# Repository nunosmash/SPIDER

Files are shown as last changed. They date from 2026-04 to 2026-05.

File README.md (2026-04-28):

[README.md](https://github.com/user-attachments/files/26697123/README.md)
# SPIDER

**BLE MIDI gateway** — bridge **Bluetooth LE MIDI** controllers to **USB MIDI** and **DIN MIDI**, with up to **three** simultaneous BLE devices, **fixed slot routing**, and **HOST** / **CLIENT** roles for stage and DAWless setups.

Part of the **Ash Sound Works** custom tools for live and studio — by sound artist and producer **Ash (Ahn Sunghoon)** · [GitHub](https://github.com/nunosmash) / 
[Manual](http://ashsoundworks.com/spider-manual.html)

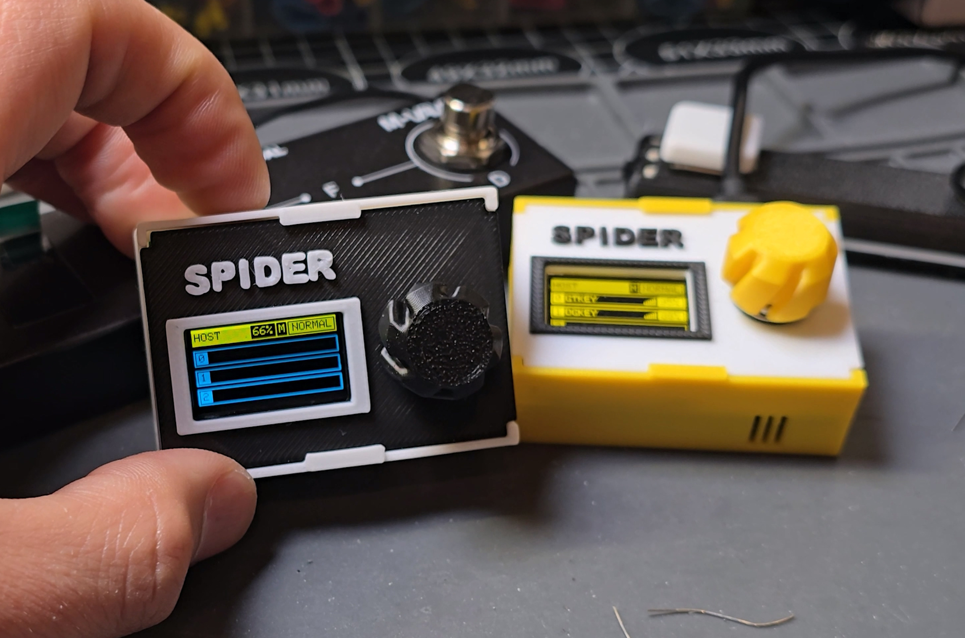
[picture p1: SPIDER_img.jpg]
SPIDER (https://youtu.be/Al2et1Eq5mc?si=DPkdCoxhtiU5xMxv)


---

## Why SPIDER?

Running cables across a crowded **pedalboard** or needing **remote** control for other players is awkward. SPIDER was built around **BLE MIDI** on a dedicated **nRF52840** radio (e.g. **nice!nano** class hardware): low power, battery-friendly, and focused on **wireless MIDI** rather than sharing the stack with a desktop OS BLE stack.

---

## Key features

- Up to **3** BLE MIDI controllers connected at once  
- **USB MIDI** via **TinyUSB** — **3 independent virtual MIDI ports** (one per slot)  
- **DIN MIDI** — **Slot 0** routes to DIN when appropriate (see routing below)  
- **7.5 ms** BLE connection interval class; low-latency slot timing (~**5 ms** average response in typical use)  
- **TX power** auto-adjust **0 ~ +8 dBm** from **RSSI**  
- **Battery monitoring** for the unit and connected gear (where supported)  
- **OLED** UI with power-save brightness (USB vs battery profiles)  
- **HOST** and **CLIENT** modes  

---

## Routing architecture

| Role | Behavior (summary) |
|---|---|
| **Slot 0 (master)** | USB ↔ BLE ↔ DIN MIDI |
| **Slots 1–2** | USB ↔ BLE |
| **Port pinning** | Each slot stores **MAC + name** so devices **always** map to the same slot regardless of power-on order |

### HOST mode

- **USB data connected:** BLE → **USB MIDI** (DIN blocked for that path per firmware logic)  
- **No USB data:** Slot 0 → **DIN MIDI** output  
- Slot management: **RESCAN**, **CLEAR SLOT**, auto-reconnect  

### CLIENT mode

- Uses **one slot** to join a host  
- Remembers first trusted host **MAC** (save window ~30 s on first connect); optional **block** for unwanted devices  

---

## OLED / status (summary)

- Top line: **LOW BAT**, **WEAK SIG**, **M** (DIN active), TX power hints  
- Per slot: **EMPTY** / **OFFLINE** / **CONNECTED**  
- MIDI traffic: ▽ in / △ out  
- Battery: **%** or **N/A** if unknown  

### Antenna bars (signal guide)

- **6–4 bars** — best; within ~**10 m** reliable  
- **3 bars** — stable for normal use  
- **≤2 bars** — TX power ramps up; maintain connection  
- **0 bars** — unreliable; move closer  

**Tip:** Keep **3+ bars** within ~**10 m** for dependable live use.

---

## Ableton Live (quick setup)

**Preferences → Link / Tempo / MIDI**

- **Input:** SPIDER MIDI **Port 1, 2, 3** → **Track** ON, **Remote** ON as needed  
- **Output:** enable if you send MIDI back to wireless gear  

| Slot | USB MIDI port |
|---|---|
| SLOT 1 | Port 1 |
| SLOT 2 | Port 2 |
| SLOT 3 | Port 3 |

---

## Sync calibration

BLE adds variable delay; align with audio using **Track Delay** like any MIDI path. Many setups start around **−10 ms ~ −20 ms** (often **−18 ms**) and refine by recording MIDI out + external audio and matching to the grid.

---

## Firmware update

1. Connect SPIDER over **USB**.  
2. Hold the **encoder button** for **5+ seconds** to enter firmware update mode (**USB mass storage** / removable drive).  
3. Copy the released firmware file to the mounted drive; device updates and reboots.  

(Exact filename and format follow your published release notes.)

---

## Use cases

- **Band live** — multiple wireless controllers into one DAW reliably  
- **DAWless** — Slot 0 → hardware synths via DIN  
- **Multi-computer** — advanced MIDI routing between several hosts (see full manual)  

---

## Repository contents

Depending on branch or release:

- Firmware (Zephyr / Arduino / etc. — match your repo)  
- Schematics / PCB / case files  
- Build and flash instructions  

Full wiring, menus, and edge cases: **`spider-manual.html`** in the Ash Sound Works bundle.

---

## Hardware Specifications (BOM)

| Category | Component Description | Qty |
| :--- | :--- | :---: |
| **MCU** | nRF52840 (nice!nano v2.0 SuperMini) | 1 |
| **Display** | 0.91" OLED Module (128x64) | 1 |
| **Optocoupler** | 6N138 High-Speed Optocoupler | 1 |
| **Diode** | 1N4001 Rectifier Diode | 1 |
| **Capacitor** | 100μF Electrolytic Capacitor | 1 |
| **Input** | EC11 Rotary Encoder w/ Push Switch | 1 |
| **Connectors** | PJ-320A 3.5mm Stereo Jack | 2 |
| **Power** | SS-12F23 Slide Switch | 1 |
| **Resistors** | 220Ω (x2), 330Ω (x2), 150Ω, 1kΩ, 4.7kΩ, 10Ω, 30Ω | 9 |

## Documentation

- Full manual: `spider-manual.html`  
- Other projects: [github.com/nunosmash](https://github.com/nunosmash)

---

## Disclaimer

- **BLE** performance depends on environment, antennas, and interference — always **test** before a show.  
- Verify **DIN polarity** (Type A/B) when connecting legacy MIDI gear.  
- DIY: observe battery and USB power safety.

---

## License

See the `LICENSE` file in the repository root.

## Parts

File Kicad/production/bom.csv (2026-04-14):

Designator | Footprint | Quantity | Value | LCSC Part #
1N4001 | D_DO-35_SOD27_P7.62mm_Horizontal | 1 | 1n4001
C1 | CP_Radial_D6.3mm_P2.50mm | 1 | 100uF
ENC5 | RotaryEncoder_Alps_EC11E-Switch_Vertical_H20mm | 1 | EC11
J1 | PinHeader_1x02_P2.54mm_Vertical | 1 | BATTERY
J2 | PJ-320A | 1 | MIDI IN ◁
J3 | PJ-320A | 1 | MIDI OUT
R10 | R_Axial_DIN0204_L3.6mm_D1.6mm_P7.62mm_Horizontal | 1 | 4.7k
R13, R14 | R_Axial_DIN0204_L3.6mm_D1.6mm_P7.62mm_Horizontal | 2 | 330
R19 | R_Axial_DIN0204_L3.6mm_D1.6mm_P7.62mm_Horizontal | 1 | 10
R20 | R_Axial_DIN0204_L3.6mm_D1.6mm_P7.62mm_Horizontal | 1 | 30
R4, R8 | R_Axial_DIN0204_L3.6mm_D1.6mm_P7.62mm_Horizontal | 2 | 220
R5 | R_Axial_DIN0204_L3.6mm_D1.6mm_P7.62mm_Horizontal | 1 | 150
R9 | R_Axial_DIN0204_L3.6mm_D1.6mm_P7.62mm_Horizontal | 1 | 1k
SW1 | SS-12F23 | 1 | SW_SPDT
U2 | DIP-8_W7.62mm | 1 | 6N138
U3 | 128x64OLED | 1 | OLED-I2C

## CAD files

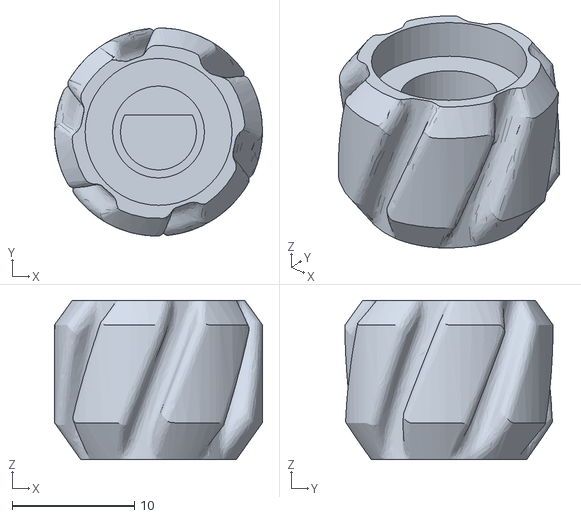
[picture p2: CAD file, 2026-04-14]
Case/SPIDER_CASE_KNOB.stl
17.0 x 17.0 x 13.0

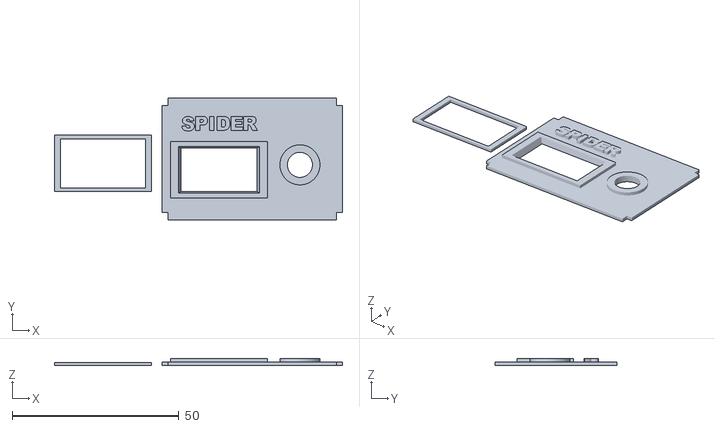
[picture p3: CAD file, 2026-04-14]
Case/SPIDER_CASE_TOP.stl
86.2 x 36.5 x 2.00

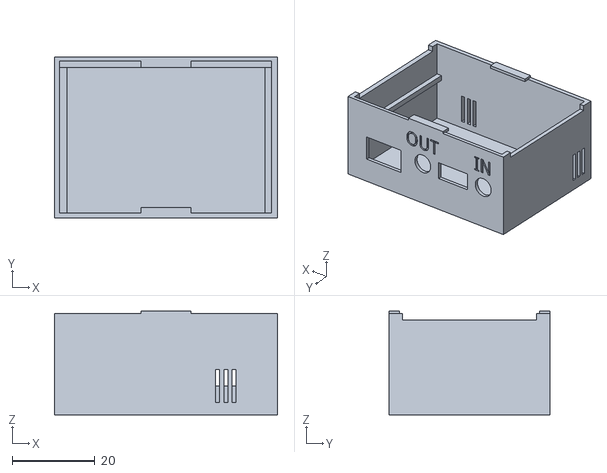
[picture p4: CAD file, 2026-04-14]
Case/SPIDER_CASE_BOTTOM(BAT).stl
54.0 x 39.0 x 25.1

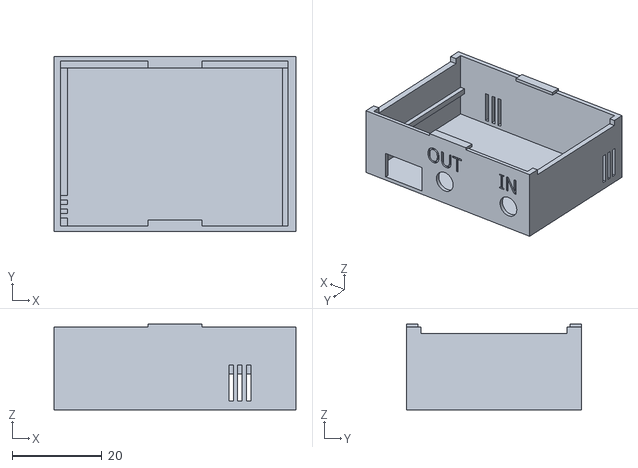
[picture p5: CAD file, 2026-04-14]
Case/SPIDER_CASE_BOTTOM.stl
54.0 x 39.0 x 19.1

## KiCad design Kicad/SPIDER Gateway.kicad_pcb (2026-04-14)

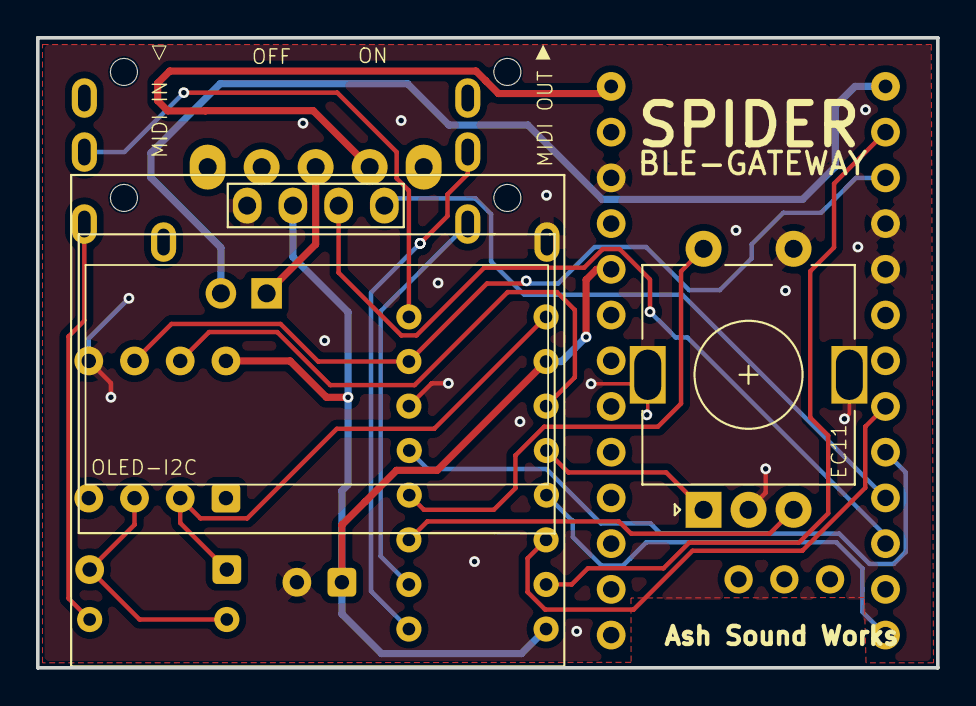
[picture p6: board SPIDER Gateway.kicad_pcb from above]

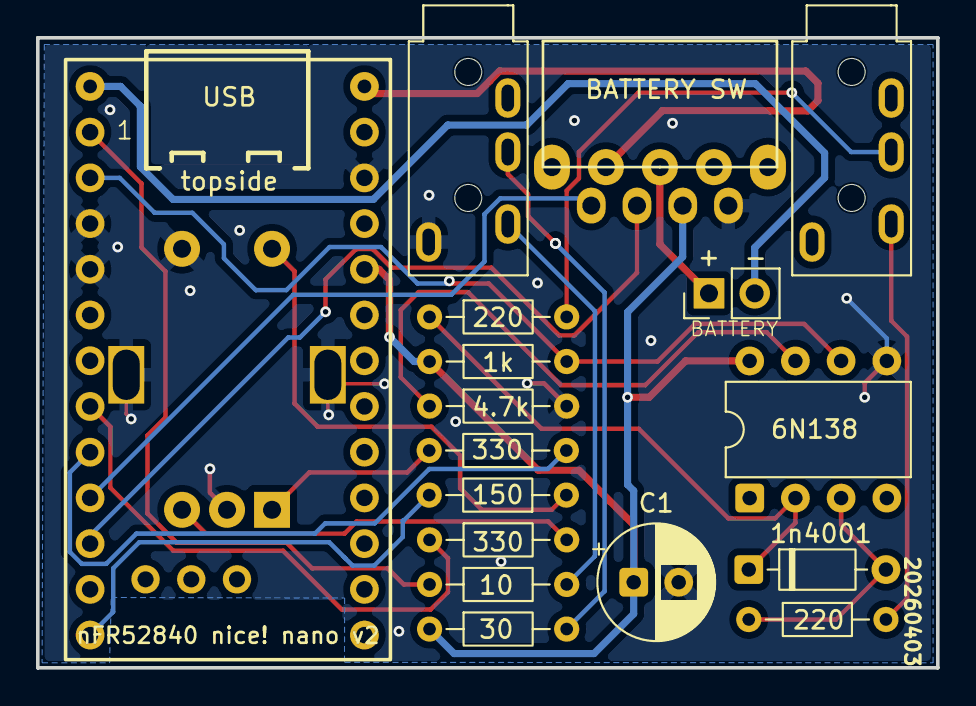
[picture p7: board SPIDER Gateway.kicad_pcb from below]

Board: 2 copper layers, 50.0 x 35.0 mm, 19 parts (17 on the bottom side), 22 nets.

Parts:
1n4001: 1n4001; D_DO-35_SOD27_P7.62mm_Horizontal
C1: 100uF; CP_Radial_D6.3mm_P2.50mm
Enc5: EC11; RotaryEncoder_Alps_EC11E-Switch_Vertical_H20mm
J1: BATTERY; PinHeader_1x02_P2.54mm_Vertical
J2: MIDI IN ◁; PJ-320A
J3: MIDI OUT; PJ-320A
R4, R8: 220; R_Axial_DIN0204_L3.6mm_D1.6mm_P7.62mm_Horizontal
R5: 150; R_Axial_DIN0204_L3.6mm_D1.6mm_P7.62mm_Horizontal
R9: 1k; R_Axial_DIN0204_L3.6mm_D1.6mm_P7.62mm_Horizontal
R10: 4.7k; R_Axial_DIN0204_L3.6mm_D1.6mm_P7.62mm_Horizontal
R13, R14: 330; R_Axial_DIN0204_L3.6mm_D1.6mm_P7.62mm_Horizontal
R19: 10; R_Axial_DIN0204_L3.6mm_D1.6mm_P7.62mm_Horizontal
R20: 30; R_Axial_DIN0204_L3.6mm_D1.6mm_P7.62mm_Horizontal
SW1: SW_SPDT; SS-12F23
U1: nFR52840 nice! nano v2; SuperMini NRF52840
U2: 6N138; DIP-8_W7.62mm
U3: OLED-I2C; 128x64OLED

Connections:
3.3V VCC: C1.1, R9.1, R20.1, U1.16 (3V3), U2.8 (VCC), U3.2 (VCC)
BATTERY +: J1.1, SW1.2 (B)
BATTERY -: J1.2, U1.28 (GND)
ENC A: R13.1, U1.8 (P0.24)
ENC B: R14.1, U1.7 (P0.22)
GND: C1.2, Enc5.C, Enc5.MP, Enc5.S1, J3.S, R10.2, U1.3 (GND), U1.4 (GND), U1.14 (GND), U2.5 (GND), U3.1 (GND)
unnamed: 1n4001.2 (A), R4.1, U2.3 (C2)
unnamed: 1n4001.1 (K), R8.1, U2.2 (C1)
unnamed: Enc5.A, R13.2
unnamed: Enc5.B, R14.2
unnamed: Enc5.S2, R5.1
unnamed: J2.R1, R8.2
unnamed: J2.T, R4.2
unnamed: J3.R1, R20.2
unnamed: J3.T, R19.2
unnamed: SW1.3 (C), U1.29 (BAT+)
unnamed: R10.1, U2.7 (VO1)
RX: R9.2, U1.2 (P0.08), U2.6 (VO2)
SCK: U1.10 (P0.11), U3.3 (SCL)
SDA: U1.9 (P1.00), U3.4 (SDA)
SW: R5.2, U1.12 (P1.06-LF)
TX: R19.1, U1.1 (P0.06)

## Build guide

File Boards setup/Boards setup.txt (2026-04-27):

How to set pin numbers for nRF52840 nice!nano v2.0

Refer to:
https://github.com/pdcook/nRFMicro-Arduino-Core?tab=readme-ov-file

Replace the variant.h and variant.cpp files located in a path similar to:
C:\Users\Administrator\AppData\Local\Arduino15\packages\adafruit\hardware\nrf52\1.7.0\variants\feather_nrf52840_express

How to change TinyUSB serial name

Raspberry Pi Pico 2
C:\Users\Administrator\AppData\Local\Arduino15\packages\rp2040\hardware\rp2040\5.4.4\libraries\Adafruit_TinyUSB_Arduino\src\arduino

nRF52840
C:\Users\Administrator\AppData\Local\Arduino15\packages\adafruit\hardware\nrf52\1.7.0\libraries\Adafruit_TinyUSB_Arduino\src\arduino

Go to the corresponding path and edit the Adafruit_USBD_CDC.cpp file.
Find setStringDescriptor("TinyUSB Serial"); and change the string inside the quotes to modify the name shown when connecting the board via serial.

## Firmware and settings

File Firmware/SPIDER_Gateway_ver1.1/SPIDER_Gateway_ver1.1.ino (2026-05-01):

// =============================================================================
// SPIDER Gateway — nRF52840 (Nice!nano) BLE MIDI bridge + OLED UI
// =============================================================================

#include <bluefruit.h>
#include <Wire.h>
#include <Adafruit_GFX.h>
#include <Adafruit_SSD1306.h>
#include <InternalFileSystem.h>
#include <Adafruit_SleepyDog.h>
#include <Adafruit_TinyUSB.h>

// -----------------------------------------------------------------------------
// USB MIDI: host(3 ports) / client(1); active pointer set in setup()
// -----------------------------------------------------------------------------
Adafruit_USBD_MIDI usb_midi_host(3);
Adafruit_USBD_MIDI usb_midi_client(1);
Adafruit_USBD_MIDI *usb_midi_ptr = nullptr;

#define MIDI_SVC_UUID_STR "03b80e5a-ede8-4b33-a751-6ce34ec4c700"
#define MIDI_CHR_UUID_STR "7772e5db-3868-4112-a1a9-f2669d106bf3"

#define MY_USB_MANUFACTURER "ASH SOUND WORKS"
#define MY_USB_PRODUCT "SPIDER"
#define MY_USB_PID 0x033A
#define MY_USB_SERIAL "0001"
#define usb_midi (*usb_midi_ptr)

#define MAGIC_UF2_BOOTLOADER 0x57

// -----------------------------------------------------------------------------
// BLE central (host): battery client + 3x MIDI + 3x battery services
// -----------------------------------------------------------------------------
BLEClientService host_bat_svc_client(UUID16_SVC_BATTERY);
BLEClientCharacteristic host_bat_chr_client(UUID16_CHR_BATTERY_LEVEL);
BLEUuid midiSvcUuid(MIDI_SVC_UUID_STR);
BLEUuid midiChrcUuid(MIDI_CHR_UUID_STR);
BLEClientService ble_midi_svc[3] = {
  BLEClientService(midiSvcUuid), BLEClientService(midiSvcUuid), BLEClientService(midiSvcUuid)
};
BLEClientCharacteristic ble_midi_chr[3] = {
  BLEClientCharacteristic(midiChrcUuid), BLEClientCharacteristic(midiChrcUuid), BLEClientCharacteristic(midiChrcUuid)
};
BLEClientService ble_bat_svc[3] = {
  BLEClientService(UUID16_SVC_BATTERY), BLEClientService(UUID16_SVC_BATTERY), BLEClientService(UUID16_SVC_BATTERY)
};
BLEClientCharacteristic ble_bat_chr[3] = {
  BLEClientCharacteristic(UUID16_CHR_BATTERY_LEVEL), BLEClientCharacteristic(UUID16_CHR_BATTERY_LEVEL), BLEClientCharacteristic(UUID16_CHR_BATTERY_LEVEL)
};

using namespace Adafruit_LittleFS_Namespace;

// -----------------------------------------------------------------------------
// Filesystem / scan list / pins
// -----------------------------------------------------------------------------
#define CONFIG_FILE "/slots_config.dat"
#define MAX_DEVICES 50
#define NAME_LEN 15
#define DEVICE_TIMEOUT 3000

#define SDA_PIN 6
#define SCL_PIN 7
#define VCC_EXT_PIN 21
#define ENCODER_A 4
#define ENCODER_B 5
#define BUTTON_PIN 9

// -----------------------------------------------------------------------------
// Display, encoder, UI timing
// -----------------------------------------------------------------------------
uint8_t ignoredMac[6] = { 0 };
uint32_t ignoreUntil = 0;
uint8_t pendingUnknownMac[6] = { 0 };
unsigned long pendingUnknownSince = 0;
/** 블랙리스트 중인 피어 표시용 (CLEAR&BLOCK 시 clientSlot 이름 복사) */
char ignoredPeerName[NAME_LEN] = "";
unsigned long searchStartTime = 0;
Adafruit_SSD1306 display(128, 64, &Wire, -1);
long encoderPos = 0;
/** A=bit1, B=bit0 — AB 인터럽트 전이표용 이전 상태 */
volatile uint8_t encPrevState = 0;
bool buttonState = false;
int currentSelection = -1;
unsigned long lastInteractionTime = 0;
int displayDeviceCount = 0;
uint8_t lockedMac[6] = { 0 };
bool isTargetLocked = false;
bool isBackSelected = false;
ble_gap_evt_adv_report_t device_reports[MAX_DEVICES];
unsigned long lastMidiTime[3] = { 0, 0, 0 };
unsigned long lastUsbMidiTime[3] = { 0, 0, 0 };
volatile int encoderAccumulator = 0;
/** 디텐트당 LUT 누적(보통 4; 메뉴가 2칸씩 움직이면 2로 낮춤) */
const int ENC_STEPS_PER_DETENT = 4;
unsigned long lastEncoderMoveTime = 0;
const unsigned long ENCODER_GAP = 0;
uint8_t remoteHostBat = 0;
bool blinkState = false;


// -----------------------------------------------------------------------------
// BLE peripheral (client): 128-bit MIDI UUID (little-endian byte order)
// -----------------------------------------------------------------------------
const uint8_t UUID128_SVC_MIDI[] = {
  0x00, 0xC7, 0xC4, 0x4E, 0xE3, 0x6C, 0x51, 0xA7,
  0x33, 0x4B, 0xE8, 0xED, 0x5A, 0x0E, 0xB8, 0x03
};
const uint8_t UUID128_CHR_MIDI[] = {
  0xF3, 0x6B, 0x10, 0x9D, 0x66, 0xF2, 0xA9, 0xA1,
  0x12, 0x41, 0x68, 0x38, 0xDB, 0xE5, 0x72, 0x77
};
BLEService client_midi_svc = BLEService(UUID128_SVC_MIDI);
BLECharacteristic client_midi_chr = BLECharacteristic(UUID128_CHR_MIDI);
BLEBas client_bat;
int lastRemainingSeconds = -1;

unsigned long scanStartTime = 0;
const unsigned long UI_TIMEOUT = 7000;
const unsigned long DIM_TIMEOUT = 300000;
/** 클라이언트: 플래시에 마스터 없을 때만 첫 연결 후 자동 저장까지 카운트다운(초). 15초로 줄이려면 15000UL */
const unsigned long CLIENT_TRUST_SAVE_MS = 30000UL;
bool isDimmed = false;
String pendingName = "";
char errorMsg[20] = "";
unsigned long errorMsgUntil = 0;
/** BLE 콜백에서 OLED(I2C)를 직접 건드리지 않고, loop()에서 updateDisplay()만 호출하도록 요청 */
volatile bool g_displayRefreshRequest = false;
static bool g_displayReady = false;

enum SystemMode { MODE_HOST,
                  MODE_CLIENT };

SystemMode loadSystemMode();
void showSetupProgress(const char *msg);
void setupHostMode();
void setupClientMode();

enum TxPowerMode { POWER_NORMAL,
                   POWER_STRONG,
                   POWER_BOOST };
TxPowerMode currentTxMode = POWER_NORMAL;
int8_t activeTxPower = 0;

enum ConnectionMatchMode { MATCH_MAC_ONLY = 0,
                           MATCH_MAC_AND_NAME = 1 };
ConnectionMatchMode currentConnectionMatchMode = MATCH_MAC_AND_NAME;
void drawConnectionModeMenu();
void saveConnectionMatchMode(ConnectionMatchMode mode);
ConnectionMatchMode loadConnectionMatchMode();
void drawEncoderDirectionMenu();
void drawSetupMenu();
void saveEncoderReversed(bool reversed);
bool loadEncoderReversed();

struct Device {
  uint8_t mac[6];
  int8_t rssi;
  char name[NAME_LEN];
  unsigned long lastSeen;
};

enum State { MAIN_MENU,
             SLOT_MENU,
             SCAN_MENU,
             MODE_SELECT,
             CLIENT_MENU,
             CONNECTION_MODE_MENU,
             ENCODER_DIRECTION_MENU,
             SETUP_MENU };
State currentState = MAIN_MENU;
SystemMode currentSystemMode = MODE_HOST;
int modeSelection = 0;
int clientMenuSelection = 0;
unsigned long buttonPressStartTime = 0;
bool isEncoderReversed = false;

enum SlotStatus { EMPTY,
                  OFFLINE,
                  CONNECTED };

struct Slot {
  SlotStatus status;
  char name[NAME_LEN];
  uint8_t mac[6];
  int8_t battery;
};

struct SystemSettings {
  uint8_t savedMasterMac[6];
  char savedMasterName[NAME_LEN];
  bool hasSavedMaster;
};

SystemSettings config = { { 0 }, "", false };
unsigned long connectionStartTime = 0;
bool isMasterSavedThisSession = false;
typedef Slot SlotConfig;

int slotMenuSelection = 0;
int selectedSlotIdx = -1;
int scanMenuSelection = 0;
int connectionModeSelection = 0;
int encoderDirectionSelection = 0;
int setupMenuSelection = 0;

bool macEqual(const uint8_t *a, const uint8_t *b) {
  for (int i = 0; i < 6; i++) {
    if (a[i] != b[i]) return false;
  }
  return true;
}

// -----------------------------------------------------------------------------
// Slots & scan device list
// -----------------------------------------------------------------------------
Slot slots[3] = {
  { EMPTY, "", { 0 }, -1 },
  { EMPTY, "", { 0 }, -1 },
  { EMPTY, "", { 0 }, -1 }
};
Slot clientSlot = { EMPTY, "", { 0 }, -1 };

bool isScanRequired() {
  if (currentState == SCAN_MENU) return true;
  for (int i = 0; i < 3; i++) {
    if (slots[i].status == OFFLINE) return true;
  }
  return false;
}

Device devices[MAX_DEVICES];
int deviceCount = 0;

// -----------------------------------------------------------------------------
// Config file (host slots + client master info)
// -----------------------------------------------------------------------------
void saveConfig() {
  Watchdog.reset();
  SlotConfig toSave[3];

  if (currentSystemMode == MODE_CLIENT) {
    Adafruit_LittleFS_Namespace::File readFile(CONFIG_FILE, FILE_O_READ, InternalFS);
    if (readFile) {
      readFile.read((uint8_t *)toSave, sizeof(toSave));
      readFile.close();
    } else {
      memset(toSave, 0, sizeof(toSave));
    }
  } else {
    for (int i = 0; i < 3; i++) {
      toSave[i].status = slots[i].status;
      memcpy(toSave[i].mac, slots[i].mac, 6);
      strncpy(toSave[i].name, slots[i].name, NAME_LEN - 1);
    }
  }

  InternalFS.remove(CONFIG_FILE);
  Adafruit_LittleFS_Namespace::File file(CONFIG_FILE, FILE_O_WRITE, InternalFS);
  if (file) {
    file.write((uint8_t *)toSave, sizeof(toSave));
    file.write((uint8_t *)&config, sizeof(config));
    file.close();
    Serial.println("Flash Config Saved (Mode Isolated)");
  }
}
void loadConfig() {
  InternalFS.begin();
  Adafruit_LittleFS_Namespace::File file(CONFIG_FILE, FILE_O_READ, InternalFS);

  if (file) {
    SlotConfig loaded[3];
    memset(&config, 0, sizeof(config));
    file.read((uint8_t *)loaded, sizeof(loaded));
    size_t cfgRead = file.read((uint8_t *)&config, sizeof(config));
    file.close();
    if (cfgRead != sizeof(config)) {
      memset(&config, 0, sizeof(config));
      config.hasSavedMaster = false;
      Serial.println(F("Config tail missing or old file — master pairing reset"));
    }

    for (int i = 0; i < 3; i++) {
      slots[i].status = loaded[i].status;
      // CONNECTED 상태로 저장되었어도 부팅 시에는 일단 찾기 전까지 OFFLINE으로 설정
      if (slots[i].status == CONNECTED) {
        slots[i].status = OFFLINE;
      }
      strncpy(slots[i].name, loaded[i].name, NAME_LEN - 1);
      slots[i].name[NAME_LEN - 1] = '\0';
      memcpy(slots[i].mac, loaded[i].mac, 6);
    }
    Serial.println("Config loaded from Flash!");
  } else {
    Serial.println("No config file found (First boot)");
  }
}
void removeOldDevices() {
  unsigned long now = millis();
  for (int i = 0; i < deviceCount;) {
    // 마지막으로 발견된 지 5초(DEVICE_TIMEOUT)가 지났다면
    if (now - devices[i].lastSeen > DEVICE_TIMEOUT) {
      // 리스트에서 삭제 (뒤의 항목들을 앞으로 당김)
      // 중요: devices[]와 device_reports[]의 인덱스를 항상 함께 유지해야
      // 선택한 스캔 항목이 올바른 peer report로 연결됩니다.
      for (int j = i; j < deviceCount - 1; j++) {
        devices[j] = devices[j + 1];
        device_reports[j] = device_reports[j + 1];
      }
      deviceCount--;
      // 인덱스 i는 증가시키지 않음 (당겨진 다음 항목을 검사해야 하므로)
    } else {
      i++;
    }
  }
}

void parseName(ble_gap_evt_adv_report_t *report, char *name) {
  uint8_t *data = report->data.p_data;
  uint8_t len = report->data.len;

  name[0] = 0;
  char shortLocal[NAME_LEN] = { 0 };

  for (int i = 0; i < len;) {
    uint8_t field_len = data[i];
    if (field_len == 0 || (i + 1 + field_len) > len) break;
    uint8_t field_type = data[i + 1];

    if (field_type == 0x09) {
      int n = (int)field_len - 1;
      if (n < 0) n = 0;
      if (n >= NAME_LEN) n = NAME_LEN - 1;
      memcpy(name, &data[i + 2], n);
      name[n] = 0;
      return;
    }
    if (field_type == 0x08 && shortLocal[0] == 0) {
      int n = (int)field_len - 1;
      if (n < 0) n = 0;
      if (n >= NAME_LEN) n = NAME_LEN - 1;
      memcpy(shortLocal, &data[i + 2], n);
      shortLocal[n] = 0;
    }

    i += field_len + 1;
  }
  if (name[0] == 0 && shortLocal[0] != 0) {
    strncpy(name, shortLocal, NAME_LEN - 1);
    name[NAME_LEN - 1] = 0;
  }
}

// OLED 슬롯 행 안테나 막대: 6단(0=없음 … 6=만칸). 가로 폭 ≈4칸 때와 비슷(간격 2px).
enum { ANT_RSSI_BAR_MAX = 6 };

static int antennaBarsFromRssi(float rssi, int lastBars) {
  int c = lastBars;
  if (c > ANT_RSSI_BAR_MAX) c = ANT_RSSI_BAR_MAX;
  if (c < 0) c = 0;
  if (rssi > (c == 5 ? -55 : -58)) return 6;
  if (rssi > (c == 4 ? -61 : -64)) return 5;
  if (rssi > (c == 3 ? -67 : -70)) return 4;
  if (rssi > (c == 2 ? -73 : -76)) return 3;
  if (rssi > (c == 1 ? -79 : -82)) return 2;
  if (rssi > (c == 0 ? -88 : -91)) return 1;
  if (rssi <= -94) return 0;
  return c;
}

static void drawAntennaBars(int antX, int y, int bars, uint16_t color) {
  const int spacing = 2;
  for (int b = 0; b < ANT_RSSI_BAR_MAX; b++) {
    if (b < bars) {
      // 맨 오른쪽(최장)만 예전과 동일 8px, 나머지는 각 +1px (3,4,5,6,7,8)
      int h_val = 3 + b;
      display.drawFastVLine(antX + b * spacing, y + 11 - h_val, h_val, color);
    }
  }
}

void updateDevice(ble_gap_evt_adv_report_t *report, int8_t rssi, char *name) {
  uint8_t *mac = report->peer_addr.addr;

  // 1. 이미 슬롯(1~4번)에 등록된 기기인지 확인
  bool isStoredInSlot = false;
  for (int i = 0; i < 3; i++) {
    // [중요] 상태가 EMPTY가 아닐 때만 슬롯 기기로 인정
    if (slots[i].status != EMPTY && macEqual(slots[i].mac, mac)) {
      isStoredInSlot = true;
      break;
    }
  }

  // 등록되지 않은 기기인데 신호가 너무 약하면 무시
  if (!isStoredInSlot && rssi < -85) return;

  // 2. 리스트 업데이트 (스캔 메뉴용)
  for (int i = 0; i < deviceCount; i++) {
    if (macEqual(devices[i].mac, mac)) {
      devices[i].rssi = rssi;
      devices[i].lastSeen = millis();
      memcpy(&device_reports[i], report, sizeof(ble_gap_evt_adv_report_t));
      return;
    }
  }

  // 새 장치 추가
  if (deviceCount < MAX_DEVICES) {
    memcpy(devices[deviceCount].mac, mac, 6);
    devices[deviceCount].rssi = rssi;
    strncpy(devices[deviceCount].name, name, NAME_LEN - 1);
    devices[deviceCount].name[NAME_LEN - 1] = '\0';
    devices[deviceCount].lastSeen = millis();
    memcpy(&device_reports[deviceCount], report, sizeof(ble_gap_evt_adv_report_t));
    deviceCount++;
  }
}

void scan_callback(ble_gap_evt_adv_report_t *report) {
  char name[NAME_LEN];
  parseName(report, name);

  // 이름이 AD에 없는 패킷(스캔 응답 전용 등)에서도 MAC만 맞으면 재연결 시도
  for (int i = 0; i < 3; i++) {
    if (slots[i].status == OFFLINE && macEqual(slots[i].mac, report->peer_addr.addr)) {
      Serial.printf("Slot %d device found! Attempting Auto-Connect...\n", i + 1);
      Bluefruit.Scanner.stop();
      Bluefruit.Central.connect(report);
      return;
    }
  }

  if (strlen(name) == 0) {
    Bluefruit.Scanner.resume();
    return;
  }

  // MAC 자동재연결이 아니면, OFFLINE 슬롯 이름 fallback 자동연결(모호성 없을 때만) 시도
  int nameMatchSlot = -1;  // -1: none, -2: ambiguous
  for (int i = 0; i < 3; i++) {
    if (slots[i].status == OFFLINE && slots[i].name[0] != '\0' &&
        strncasecmp(slots[i].name, name, NAME_LEN - 1) == 0) {
      if (nameMatchSlot == -1) nameMatchSlot = i;
      else nameMatchSlot = -2;
    }
  }

  if (nameMatchSlot >= 0) {
    Serial.printf("Slot %d name fallback found! Attempting Auto-Connect (MAC unchanged)...\n", nameMatchSlot + 1);
    Bluefruit.Scanner.stop();
    Bluefruit.Central.connect(report);
    return;
  }

  updateDevice(report, report->rssi, name);
  Bluefruit.Scanner.resume();
}

void drawSlotMenu() {
  display.fillRect(0, 0, 128, 14, WHITE);
  display.setTextColor(BLACK);
  display.setCursor(2, 4);
  display.print("SLOT");
  drawInvertedNumber(display.getCursorX() + 2, 3, selectedSlotIdx + 1);
  display.setTextColor(BLACK);
  display.println(" SETTINGS");

  display.drawRect(0, 16, 128, 48, WHITE);

  // 순서를 BACK을 맨 위로 변경
  const char *options[] = { "<< BACK", "RESCAN DEVICE", "CLEAR SLOT" };

  for (int i = 0; i < 3; i++) {
    int yPos = 24 + (i * 12);  // 24(BACK), 36(RESCAN), 48(CLEAR)
    if (slotMenuSelection == i) {
      display.fillRect(2, yPos - 1, 124, 11, WHITE);
      display.setTextColor(BLACK);
    } else {
      display.setTextColor(WHITE);
    }
    display.setCursor(5, yPos);
    display.println(options[i]);
  }
}

/** 블랙리스트 안내 — 예전과 동일: 기본 폰트 size1, 줄 위치 y+16 / y+28 / y+40, 제목 BLOCKED */
static void drawBlockedDevicePanelForSlotY(int y, int secLeft) {
  display.setTextSize(1);
  display.setTextColor(WHITE);

  const char *hdr = "BLOCKED";
  int hw = (int)strlen(hdr) * 6;
  display.setCursor((128 - hw) / 2, y + 16);
  display.print(hdr);

  char lineName[NAME_LEN];
  strncpy(lineName, ignoredPeerName, NAME_LEN - 1);
  lineName[NAME_LEN - 1] = '\0';
  if (lineName[0] == '\0') {
    snprintf(lineName, sizeof(lineName), "ID:%02X%02X%02X", ignoredMac[2], ignoredMac[1], ignoredMac[0]);
  }
  size_t nl = strlen(lineName);
  if (nl > 18) {
    lineName[18] = '\0';
    nl = 18;
  }
  int nw = (int)nl * 6;
  display.setCursor((128 - nw) / 2, y + 28);
  display.print(lineName);

  char tbuf[16];
  snprintf(tbuf, sizeof(tbuf), "%ds LEFT", secLeft);
  int tw = (int)strlen(tbuf) * 6;
  display.setCursor((128 - tw) / 2, y + 39);
  display.print(tbuf);
}
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
void loop() {
  Watchdog.reset();
  unsigned long now = millis();
  // --- [추가] USB 상태 변화 감지 로직 ---
  static bool lastUsbMounted = false;
  bool currentUsbMounted = TinyUSBDevice.mounted();
  if (currentUsbMounted != lastUsbMounted) {
    lastUsbMounted = currentUsbMounted;
  }
  // 1. 모든 데이터 입력 및 시간 갱신 (최우선)
  handleExternalMidiIn();
  handleEncoder(now);
  handleButton(now);

  // 2. [핵심] 프레임 제한 + BLE 콜백에서 요청 시 즉시 갱신 (OLED는 loop에서만 I2C)
  if (g_displayRefreshRequest || (now - lastDisplayMillis >= DISPLAY_INTERVAL)) {
    updateDisplay();
    lastDisplayMillis = now;
    if (g_displayRefreshRequest) {
      g_displayRefreshRequest = false;
    }
  }

  // 3. 나머지 무거운 로직들 (RSSI, 배터리 등)
  handleUITimeout(now);
  handleOLEDDimming(now);
  if (currentSystemMode == MODE_HOST) loopHostMode(now);
  else loopClientMode(now);
}

void host_bat_rx_callback(BLEClientCharacteristic *chr, uint8_t *data, uint16_t len) {
  if (len > 0) {
    remoteHostBat = data[0];  // 수신된 값을 전역 변수에 저장
    Serial.printf("Received Host Battery: %d%%\n", remoteHostBat);
  }
}
// ==========================================
// [HOST] 호스트 모드 전용 루프 로직
// ==========================================
void loopHostMode(unsigned long now) {
  static unsigned long lastHostBatSend = 0;
  if (now - lastHostBatSend > 60000) {
    lastHostBatSend = now;
    updateHostBattery();
  }

  // 1. 오프라인 슬롯 체크 (2초 주기)
  checkOfflineSlots(now);
  manageScanner(now);
  // 2. 스캐너 및 연결 전력 관리
  bool scanNeeded = isScanRequired();
  bool inScanMenu = (currentState == SCAN_MENU);
  bool anyConnected = false;
  bool hasOfflineSlot = false;
  for (int i = 0; i < 3; i++) {
    if (slots[i].status == CONNECTED) {
      anyConnected = true;
    } else if (slots[i].status == OFFLINE) {
      hasOfflineSlot = true;
    }
  }

  // 일부 슬롯이 끊긴 상태(부분 오프라인)에서는 재연결 우선으로 BOOST를 강제한다.
  if (anyConnected && hasOfflineSlot) {
    if (activeTxPower != 8) {
      activeTxPower = 8;
      currentTxMode = POWER_BOOST;
      Bluefruit.setTxPower(8);
    }
  }
  // 오프라인 슬롯이 없을 때만 RSSI 기반 가변 전력 사용
  else if (anyConnected) {
    monitorHostRssi(now);
  }

  if (scanNeeded || inScanMenu) {
    // "전부 오프라인(연결 0)" 구간에서만 절전 타이머를 누적한다.
    // 하나라도 연결되면 RSSI 가변 제어를 우선하고 타이머는 리셋한다.
    if (!anyConnected) {
      if (scanStartTime == 0) scanStartTime = now;

      // 수동 스캔 메뉴가 아닐 때만 20분 절전(NORMAL) 적용
      if (!inScanMenu && (now - scanStartTime > 1200000UL)) {
        if (activeTxPower != 0) {
          activeTxPower = 0;
          currentTxMode = POWER_NORMAL;
          Bluefruit.setTxPower(0);
        }
      } else {
        if (activeTxPower != 8) {
          activeTxPower = 8;
          currentTxMode = POWER_BOOST;
          Bluefruit.setTxPower(8);
        }
      }
    } else {
      scanStartTime = 0;
    }

    // [핵심 수정] 스캐너 실행 조건: 스캔이 필요하거나 사용자가 스캔 메뉴에 있을 때
    if (!Bluefruit.Scanner.isRunning()) {
      // 스캔 메뉴일 때는 즉시 시작, 자동 연결 중일 때는 헬퍼 함수 로직에 따름
      Bluefruit.Scanner.start(0);
      Serial.println(">>> Scanner Started (Host Mode) <<<");
    }
  } else {
    // 모든 기기 연결됨 & 메뉴 밖임 -> 타이머 리셋 및 가변 전력 모니터링
    scanStartTime = 0;

    // 스캔이 필요 없는 상황이면 스캐너 중지 (자원 절약)
    if (Bluefruit.Scanner.isRunning()) {
      Bluefruit.Scanner.stop();
    }
  }
}

// ==========================================
// [CLIENT] 클라이언트 모드 전용 루프 로직
// ==========================================
void loopClientMode(unsigned long now) {
  checkSearchPowerTimeout(now);

  if (ignoreUntil != 0 && millis() >= ignoreUntil) {
    memset(ignoredMac, 0, 6);
    ignoreUntil = 0;
    ignoredPeerName[0] = '\0';
  }

  // 1. 마스터 정보 자동 저장 로직 (30초 카운트다운)
  // loop() 맨 앞의 now는 BLE connect_callback 이후면 "과거"라서
  // elapsed = now - connectionStartTime 이 unsigned 언더플로 → 곧바로 저장되는 버그가 남.
  // 반드시 이 블록에서는 millis()로 경과 시간을 잰다.
  if (Bluefruit.connected() && !isMasterSavedThisSession && connectionStartTime != 0) {
    unsigned long tmono = millis();
    unsigned long elapsed = (tmono >= connectionStartTime) ? (tmono - connectionStartTime) : 0;

    if (elapsed < CLIENT_TRUST_SAVE_MS) {
      int remaining = (int)(CLIENT_TRUST_SAVE_MS / 1000UL) - (int)(elapsed / 1000UL);
      if (remaining < 0) remaining = 0;
      if (remaining != lastRemainingSeconds) {
        lastRemainingSeconds = remaining;
      }
    } else {
      memcpy(config.savedMasterMac, clientSlot.mac, 6);
      strncpy(config.savedMasterName, clientSlot.name, NAME_LEN - 1);
      config.savedMasterName[NAME_LEN - 1] = '\0';
      config.hasSavedMaster = true;
      saveConfig();

      isMasterSavedThisSession = true;
      connectionStartTime = 0;
      lastRemainingSeconds = 0;
      strncpy(errorMsg, "MASTER SAVED!", 19);
      errorMsgUntil = tmono + 2000;
      Serial.println(F(">>> AUTO SAVE COMPLETE <<<"));
    }
  }

  // 2. 연결 상태 유지 및 배터리/RSSI 업데이트 (통합 틱)
  static unsigned long lastClientTick = 0;
  static unsigned long lastBatCheck = 0;

  // 2초마다 실행되는 관리 블록
  if (now - lastClientTick > 2000) {
    lastClientTick = now;

    if (Bluefruit.connected()) {
      // (1) RSSI 모니터링 (무선 신호 세기 측정)
      BLEConnection *conn = Bluefruit.Connection(0);
      if (conn) conn->monitorRssi();

      // (2) 배터리 잔량 업데이트 (1분마다 실행)BLE brg
      if (now - lastBatCheck > 60000 || lastBatCheck == 0) {
        lastBatCheck = now;

        uint8_t level = readHostBattery();
        client_bat.write(level);

        Serial.print(F(">>> Client Battery Updated: "));
        Serial.print(level);
        Serial.println(F("% <<<"));
      }
    }
  }
}
